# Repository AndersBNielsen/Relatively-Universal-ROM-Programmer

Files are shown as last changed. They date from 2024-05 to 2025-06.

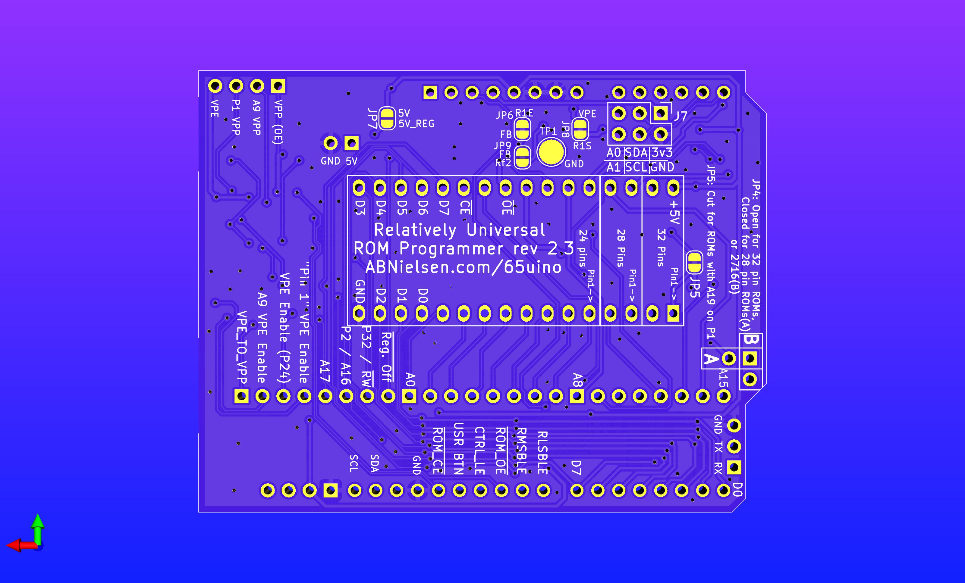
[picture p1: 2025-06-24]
hardware/RelativelyUniversalROMProgrammerRev2.3-back.jpg

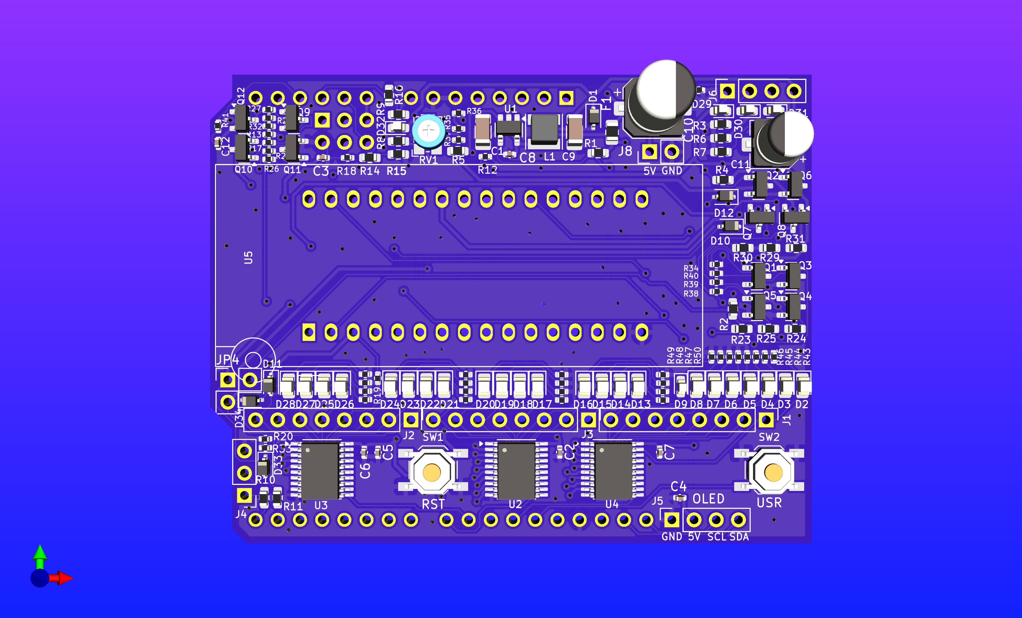
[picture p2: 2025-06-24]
hardware/RelativelyUniversalROMProgrammerRev2.3.jpg

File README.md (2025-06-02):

# Relatively Universal-ROM-Programmer
 
This is meant to be a cheap way to program W27C512 EEPROMs which require 14V erasure voltage and 12V programming voltage... Or basically any other 24/28/32 pin ROM requiring from 5V to 27V programming/erasure voltage. 

You can either make your own, get a PCB from JLCPCB using the guide below or order a kit with SMD components presoldered from [iMania.dk](https://www.imania.dk/index.php?currency=EUR&cPath=204&sort=5a&language=en) (sockets available if needed).
Kits with SMD components presoldered are available from my store, [iMania.dk](https://www.imania.dk/index.php?currency=EUR&cPath=204&sort=5a&language=en)

Requires a dev board with a processor or microcontroller. Like a [65uino](https://github.com/AndersBNielsen/65uino) or Arduino Uno for instance. 

## Software

#1 Don't attach the Programmer shield while power is on.

#2 Don't turn on power if the controller (Arduino/65uino/Nucleo board) isn't programmed with appropriate firmware. 

#3 Don't insert a ROM in the socket until you're ready to write it. Don't leave a ROM in the socket during reset or programming. 

### Firestarter firmware
If you just want to get started fast, there's an amazing third party firmware and desktop software available in the form of Henols's [Firestarter](https://github.com/henols/firestarter)
Firestarter is recommended if you just want to program ROMs cheaply, easily, and don't care too much about the technical details. 

Remember: Don't insert a ROM in the socket until you're ready to write it. Don't leave a ROM in the socket during reset or programming. Program Arduino before attaching shield. Attach shield before powering on Arduino. 

### Original proof of concept code

6502 assembly code is available in the [65uino repo](https://github.com/AndersBNielsen/65uino) (to be separated and moved here "soon"). 

Arduino sketch is available in this repo's [/software](https://github.com/AndersBNielsen/Relatively-Universal-ROM-Programmer/tree/main/software/Arduino/ArduinoProgrammerFirmwarePrototype)

Both the 6502 firmware (65uino) and the Arduino sketch use the command line python scripts in this repo for burning and reading ROMs. 

read_binary.py reads a ROM via serial. 

send_binary.py burns a ROM via serial.

send_command.py issues commands (erase for instance)

## Rev 0 photos (The Rev 1 added a voltage divider for reading VPP/VEP, Rev2 has replaced the jumpers with transistors for automatic pin count selection)

Relatively-Universal-ROM-programmer-rev0-front-assembled
Romprogrammer-assembled-back
ROMprogrammer-assembled

## Documentation
The Relatively Universal ROM Programmer relies on the standard JEDEC ROM footprint and common "high voltage" pins to work. BJT drivers handle putting the 12-27V programming voltage on the relevant pins. Which "high voltage" pins are active can be selected in software and BJT drivers control which pins can be used as VCC. 
The 12-27V for programming is manually set using a small screwdriver and a trimpot with a readout in software or multimeter if your micro doesn't have analog pins (65uino).

## Jumpers

### Revision 2.X
Revision 2 and later doesn't need physical jumpers to select 24, 28 and 32 pin ROMs, as it has transistor drivers to pass either VCC or the appropriate address line to the correct physical pin.

Revision 2 and 2.1 *do* however have a jumper to connect high voltage to pin 1 of 28 pin ROMs (JP4) - do *NOT* leave this jumper in place when programming 32 pin ROMs as it will most likely damage the ROM, the programmer, or both. 

JP4

Revision 2.2 also has JP4 but rotated 90 degrees (green) and another option of powering the VPP pin of 2716-type ROMs (red). 
Again: *DO NOT* leave JP4 in place in either rotation if you are not programming 28 pin ROMs with VPP on pin 1 (check the ROM's datasheet or "firestarter info") or 2716 type ROMs with a very nonstandard VPP pin. 



### Revision 1.x
Revision 1.x require physical jumpers to connect VCC to 24 and 28 pin ROMs

A common configuration is to connect "A" to 5V and B to "A13", which covers the Winbond 27C512 and many other common 28 pin ROMs. This configuration also covers the 32 pin SST39SF010 (5V programmable).

Documentation is on the back of Revision 1.x boards


### Setting the voltage 

The "high voltage", VPE, is calibrated using the trimpot on the front of the board after activating the regulator in software. Please be aware that some dev boards WILL put VPE on several pins during reset - especially if reset is held down manually. This MAY damage a chip in the socket (especially if it's only 5V programmable). 
Clarity: It's best to NOT reset the controller with a ROM in the socket to be on the safe side. 

Documentation will be updated with FAQ.

Programmer-back-documentation

## Getting a PCB
This project is kindly sponsored by JLCPCB. They offer cheap, professional looking PCBs and super fast delivery.

Step 1: Get the gerber file zip package from the /hardware folder
/hardware/rev2/rev2-1316.zip for instance.

Step 2: Upload to JLCPCB [https://jlcpcb.com](https://jlcpcb.com/?from=Anders_N)

Upload

Step 3: Pick your color, surface finish and order.

Select settings

Save your choice

If you want JLCPCB to assemble a board, the BOM and placement files are also in the repo. 

You can use these affiliate links to get a board for $2 and also get $80 worth of New User Coupons at: https://jlcpcb.com/?from=Anders_N

And in case you also want to order a 3D-printed case you can use this link. 
How to Get a $7 3D Printing Coupon: https://jlc3dp.com/?from=Anders_N

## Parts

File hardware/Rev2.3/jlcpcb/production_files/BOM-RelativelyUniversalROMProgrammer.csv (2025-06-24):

Comment | Designator | Footprint | LCSC | Quantity
10uF | C1,C9 | C_1206_3216Metric | C13585 | 2
28/32 pin ROM | U5 | DIP_Socket-32_W11.9_W12.7_W15.24_W17.78_W18.5_3M_232-1285-00-0602J | C146583 | 1
100nF | C12,C2,C3,C4,C5,C6,C7,C8 | C_0402_1005Metric | C1525 | 8
MIC2288 | U1 | SOT-23-5 | C181783 | 1
1N5819 | D1,D10,D11,D12,D33,D34 | D_SOD-323 | C191023 | 6
MMBT3904 | Q1,Q11,Q3,Q4,Q5,Q9 | SOT-23 | C20526 | 6
220uF | C10 | CP_Elec_6.3x7.7 | C22388053 | 1
RED | D29,D30,D31,D32,D9 | LED_0603_1608Metric | C2286 | 5
GREEN | D13,D14,D15,D16,D17,D18,D19,D2,D20,D21,D22,D23,D24,D25,D26,D27,D28,D3,D4,D5,D6,D7,D8 | LED_0805_2012Metric | C2297 | 23
10k | R12,R19,R20,R21,R33,R41,R43,R44,R45,R46,R47,R48,R49,R50,R51,R52,R53,R54,R55,R56,R57,R58,R59,R60,R61,R62,R63,R64,R65,R66 | R_0402_1005Metric | C25744 | 30
4k7 | R13,R17,R18,R22,R26,R27,R28,R32,R34,R35,R36,R37,R38,R39,R40 | R_0402_1005Metric | C25900 | 15
74HC573 | U2,U3,U4 | TSSOP-20_4.4x6.5mm_P0.65mm | C3151971 | 3
RST | SW1,SW2 | SW_SPST_TL3342 | C318884 | 2
10uH | L1 | L_Taiyo-Yuden_MD-4040 | C497774 | 1
Polyfuse | F1 | Fuse_0805_2012Metric | C516070 | 1
MMBT3906 | Q10,Q12,Q2,Q6,Q7,Q8 | SOT-23 | C7420354 | 6
50k | RV1 | Potentiometer_Bourns_TC33X_Vertical | C913246 | 1
VP | J6 | PinSocket_1x04_P2.54mm_Vertical |  | 1
Conn_01x02 | J8 | PinHeader_1x02_P2.54mm_Vertical |  | 1
22k | R25 | R_0603_1608Metric |  | 1
MSB | J2 | PinHeader_1x08_P2.54mm_Vertical |  | 1
270k | R16 | R_0603_1608Metric |  | 1
22k | R14 | R_0603_1608Metric |  | 1
1k | R11 | R_0603_1608Metric |  | 1
NC | C11 | CP_Elec_5x5.4 |  | 1
22k | R7 | R_0603_1608Metric |  | 1
LSB | J3 | PinHeader_1x08_P2.54mm_Vertical |  | 1
22k | R6 | R_0603_1608Metric |  | 1
1k | R10 | R_0603_1608Metric |  | 1
CTRL | J1 | PinHeader_1x08_P2.54mm_Vertical |  | 1
OLED | J5 | PinSocket_1x04_P2.54mm_Vertical |  | 1
22k | R4 | R_0603_1608Metric |  | 1
22k | R8 | R_0603_1608Metric |  | 1
22k | R2 | R_0603_1608Metric |  | 1
22k | R1 | R_0603_1608Metric |  | 1
22k | R3 | R_0603_1608Metric |  | 1
22k | R30 | R_0603_1608Metric |  | 1
22k | R23 | R_0603_1608Metric |  | 1
22k | R24 | R_0603_1608Metric |  | 1
22k | R31 | R_0603_1608Metric |  | 1
22k | R29 | R_0603_1608Metric |  | 1
Ext_UART | J4 | PinHeader_1x03_P2.54mm_Vertical |  | 1
22k | R15 | R_0603_1608Metric |  | 1
22k | R9 | R_0603_1608Metric |  | 1
270k | R5 | R_0603_1608Metric |  | 1
TestPoint | TP1 | TestPoint_Pad_D3.0mm |  | 1
SAO | J7 | PinHeader_2x03_P2.54mm_Vertical |  | 1

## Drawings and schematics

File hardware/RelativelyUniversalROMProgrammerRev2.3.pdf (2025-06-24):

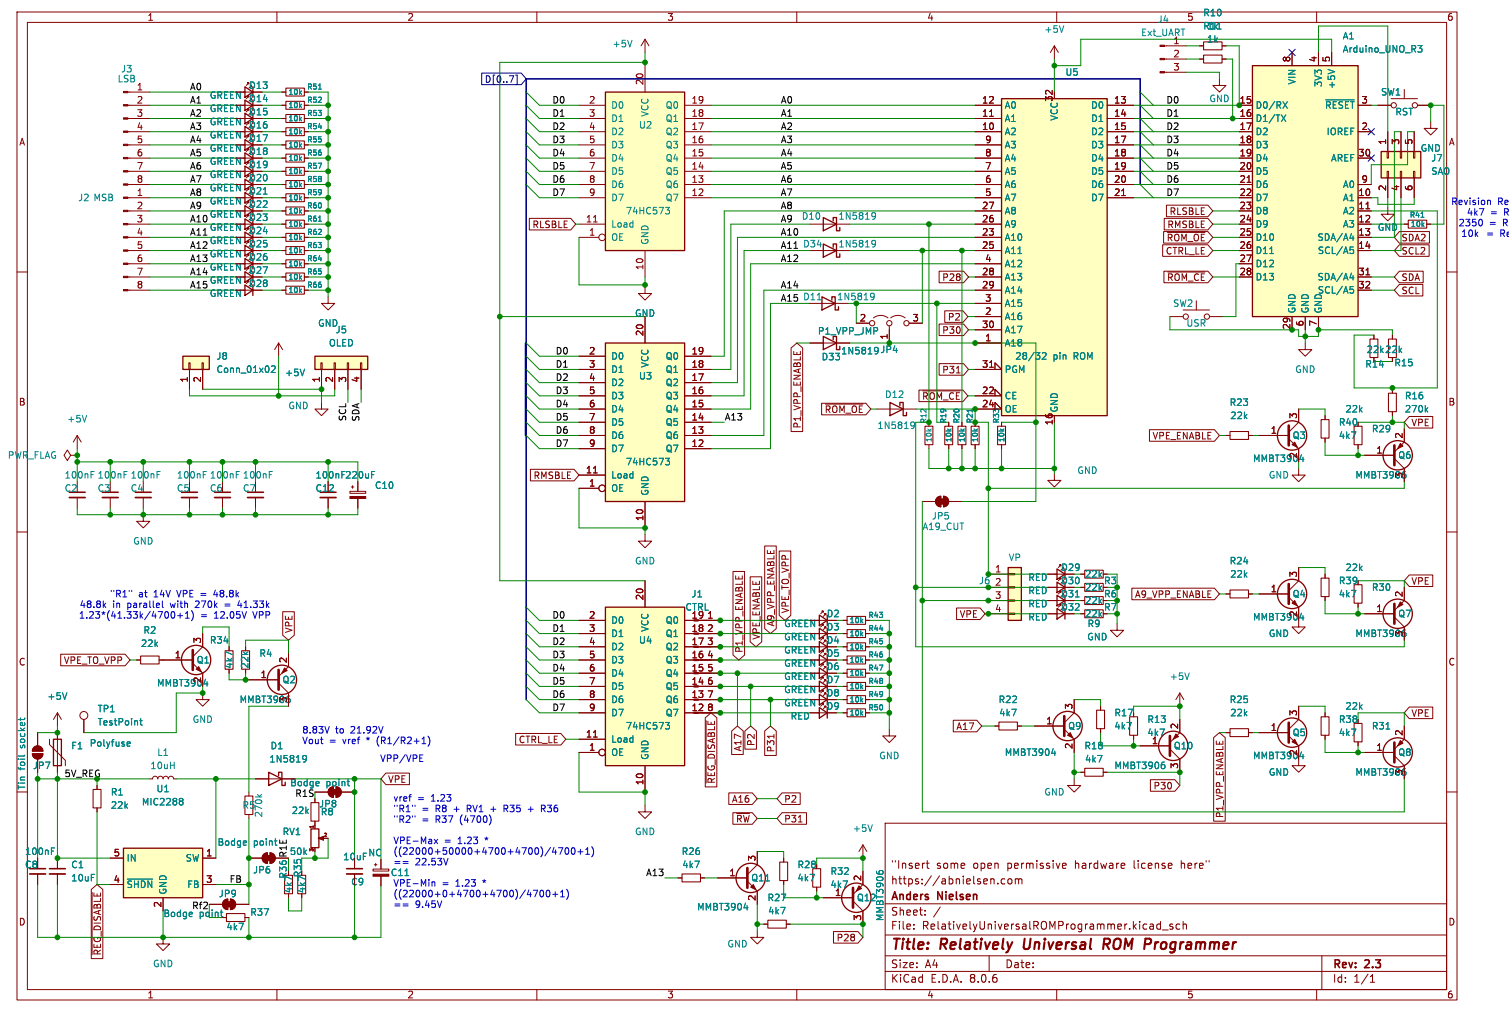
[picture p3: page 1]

~{RESET}3 AREF 30 SDA/A4 31 SCL/A5 32 3V3

A1 10 A2 11 A3 12 SDA/A4 13 SCL/A5 14 D0/RX 15 D1/TX 16 D2 17 D3 18 D4 19

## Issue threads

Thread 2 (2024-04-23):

Change github About

AndreiCherniaev, 2024-04-23:
I suggest to add About text (right top corner of github)
_Hardware to program W27C512 EEPROM or any 24/28/32 pin ROM requiring from 5V to 27V programming voltage._

I also suggest you to add tags:
**chip-programmer
prom-writer**

Closed 2024-04-23.

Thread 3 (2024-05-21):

Please please please replace the Micro-USB connector with a USB-C connector 🙏🏾

volkertb, 2024-05-21:
Hi Anders,

I just watched your announcement on YouTube, and first of all: a big THANK YOU for releasing this project with the world! :hugs:

I remember a few years ago having to find a good USB ROM programmer on-line that would come with open source Linux drivers. Although I eventually found one, it was not easy. Nor was it cheap, even for a used one.

So having a programmer that has both an open source hardware design and open source software support is really the best of both worlds. And for such a low price too! Your contribution will indeed help a lot of hobbyists, tinkerers and perhaps even some professional electronics engineers worldwide!

But I have to admit that while watching your video, there was one thing that broke my heart. And no, it wasn't the red LEDs.

The Micro-USB connector. :scream: Is there any deliberate reason why you picked it over USB-C?

There appears to be enough space in the corner to accommodate a USB-C connector instead. And it might increase the total costs of the design by a little, but I cannot imagine that it would be that much more expensive.

I don't think I have to rattle off all the advantages that USB-C has over the abomination that is Micro-USB. I think that's all pretty obvious.

Say what you will about those expensive commercial ROM programmers, but those old-school USB Type B connectors sure were durable and sturdy. I know that a Type B connector on your programmer design would probably be overkill, but please consider using USB-C in your design instead.

If there is any reason why this wouldn't be feasible, maybe you can explain in this thread?

Thanks again! Looking forward to seeing this project improve and thrive. :heart:

bleroy, 2024-05-21:
Maybe I'm missing something, but I'm pretty sure the USB connector is on whatever Arduino clone you choose to use with the board, not on the programmer board itself. Soooo.... pick a board with USB-C?

volkertb, 2024-05-21:
Ah, you're right. It goes on top of another board as a HAT. I should have realized that. :man_facepalming:

Sorry for the misunderstanding, then. In case you hadn't noticed, I hade the Micro-USB connector like the plague and got immediately triggered when I saw it as part of a new project. :sweat_smile:

Thanks for clarifying!

Closed 2024-05-21.

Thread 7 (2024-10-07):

Read ROM command not working without serial delay

BizarroBull, 2024-10-07:
When a read command is sent to the arduino, it reads a block, begins serial connection with the host, writes the header byte 0xAA, writes the block, and ends serial communication.

However, for me the header byte is never sent correctly. I have to add a `delay(50);`.

Is that expected after the `readAddress(cAddr)` calls?
I see that delay call is already there for the burn rom command and talks about settling.

AndersBNielsen, 2024-10-08:
I might be a bit sleepy but I can't seem to grasp what you are trying to do - 50ms is an eternity.  Are you using the read_binary.py script?

What exact steps are you taking to reproduce the issue?

BizarroBull, 2024-10-09:
I've created a small java gui app and I'm doing the equivalent of read_binary.py. I send the bytes to my arduino to read the ROM.

The arduino receives my bytes properly, but when it writes 0xAA followed by the block of data, the 0xAA is received in my java app as garbage. I believe the block of data is received correctly but my app ignores it since it never received 0xAA. I think it's only the first byte that isn't sent correctly.

When I add the 50ms delay, the app receives the 0xAA and the block of data correctly.

Yes, 50 ms really slows it down. I haven't tried reducing the delay further. I was hoping you might have some insight to why it would be needed and what the minimum delay would need to be.

AndersBNielsen, 2024-10-09:
Remember the Arduino resets when you open the port - that’s why it has a
long delay in the beginning.
Next you want to make sure you empty the serial buffer of all the junk
while waiting for 0xAA.
One byte at a time.

I assume you checked read_binary.py works with your Arduino and OS?
Serial kinda has a tendency to be handled differently :/

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

BizarroBull, 2024-10-09:
I wait after opening the port so that's not the issue.
My java app is emptying the serial buffer but it never receives the 0xAA byte. It receives garbage in its place.
I haven't tried your read_binary.py script. I will install python and try that.

I was thinking this was an issue with sharing pins 15 and 16 of the Arduino. Aren't the other delays in your code related to that?

BizarroBull, 2024-10-09:
I have the same problem using your python script instead of my java app. It works with my delay. It doesn't work without it.

Any thoughts?

AndersBNielsen, 2024-10-09:
Where do you insert the delay?

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

BizarroBull, 2024-10-09:
See the `delay(50);` statement in the code below:

```
      if (currentCommand.command == 0x01) {
        //Dump ROM via serial
        currentCommand.blockSize = Serial.read();
        byte cAddrL = Serial.read();
        byte cAddrH = Serial.read();
        cAddr = cAddrH << 8;
        cAddr |= cAddrL;
        romsize = (static_cast<uint32_t>(Serial.read()) << 8); //Reads stoppage a.k.a. the high byte of ROM size
        if (romsize == 0) romsize = 65536; //Need a fix to support A17+
        Serial.end();
        display.clearDisplay();
        display.print(F("Sending ROM via serial..."));
        display.print("Blocksize: ");
        display.print(currentCommand.blockSize);
        display.display();
        for (int i = 0; i < romsize/currentCommand.blockSize; i++) {
          // Read data into buffer
          for (uint16_t addr = 0; addr < currentCommand.blockSize; addr++) {
            buffer[addr] = readAddress(cAddr);
            cAddr++;
          }
          Serial.begin(baudrate);
          // delay(50); // Delay needed for Serial.write fix?
          Serial.write(0xAA);
          for (uint16_t addr = 0; addr < currentCommand.blockSize; addr++) {
            Serial.write(buffer[addr]);
          }
          Serial.end();
        }
      }
```

BizarroBull, 2024-10-10:
Would it have anything to do with the VEP (12.75V) and chip (ST 27C256) I'm using?

Is it worth watching the Arduino's D1 / TX pin with a logic analyzer while doing the readAddress followed by the Serial.begin/write?

AndersBNielsen, 2024-10-10:
You actually DO need some sort of delay there - but on the order of 1ms,
not 50.
Your serial has to time out or read a byte and stay high long enough to be
registered as inactive for the start bit to be registered correctly.
Your chip should work, easily :)

Would be helpful if you double check what’s going on in hw

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

BizarroBull, 2024-10-11:
I've moved the delay before the Serial.begin call. It works with a 1ms delay. Here you can see the read from the ROM chip, a 1 ms delay, then transmitting the data:

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

Without the delay the 0xAA looks like it's transmitted properly. My logic analyzer shows a framing error so the host receiving the data must have the same problem:

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

I can't tell from the images where the Serial.begin call was. The voltage could still be changing at that point.

AndersBNielsen, 2024-11-16:
Exactly. After transmitting junk it needs a whole frame of stop condition to know when to start.
I guess this is cleared up and this can be closed - or is it missing somewhere it should be?

BizarroBull, 2024-11-20:
The delay call needs to be added to your code.
In my comment above I show delay(50); as a comment after calling Serial.begin(baudrate).
I think it should be delay(1); BEFORE calling Serial.begin(baudrate).

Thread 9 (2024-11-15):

V2 Bom questions

tuctboh, 2024-11-15:
Hi,

Trying to get this into JLCPCB. The board was fine and I could make some changes to colors/etc, but theres BOM issues -

C11 - It says the value is NC, does this mean its not actually needed?
J5/J6 - Having an issue finding "Connector_PinSocket_2.54mm:PinSocket_1x04_P2.54mm_Vertical"
J7 - Says its not in the CPL file so they don't know how to place it
U5 - http://ww1.microchip.com/downloads/en/DeviceDoc/25022B.pdf isn't a valid url. Is the 232-1285-00-0602J the only one that can be used, they're saying its $65 each and not in stock.

Thanks, Tuc

tuctboh, 2024-11-16:
Would it also be possible to get a BOM/CPL with the bottom items populated too?  Tnx

AndersBNielsen, 2024-11-16:
There are no bottom items to be populated except for the pinheaders(which I suggest doing by hand because it's easy and it makes the board so much cheaper), so you can simply skip those. U5 is the main socket, so also a "do not place".
Be sure to deselect the headers for assembly.

Let me know if that's not enough info to get you going :)

tuctboh, 2024-11-16:
> There are no bottom items to be populated except for the pinheaders(which I suggest doing by hand because it's easy and it makes the board so much cheaper), so you can simply skip those. U5 is the main socket, so also a "do not place". Be sure to deselect the headers for assembly.
>
> Let me know if that's not enough info to get you going :)

Thanks. But I'm still looking to know -

C11 - The value says NC, does this mean its not added? It's showing up as not able to source.
J5/J6 - Do you have a better part number or description for this?
J7 - Not in the CPL file, so they don't know how to place it.
U5 - They're saying its out of stock, and its 63$ a piece. Is there a better replacement for this?

 Bottom pins+U5 - I'm not that great a solderer, so was hoping to get them to build a complete unit with no soldering needed. Is it possible to create a BOM for that.

Thanks, Tuc

AndersBNielsen, 2024-11-16:
NC means “No connect” aka don’t place.

The other pin headers you mention are debugging and not strictly needed.

It’s not that easy to have JLC solder the pins for “A1” which is the shield
pins going into the Arduino.
You might want to contact them about it - it might be expensive.

U5 is the main socket and it’s up to you if you want a generic 15.24mm wide
32 pin socket or a ZIF.
JLC don’t have ZIFs so you’ll have to send it to them.

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

tuctboh, 2024-11-16:
NC - Ok, thanks.
J5/J6 - Gotcha, but still, would rather have a COMPLETE unit incase there is a time I want to debug something stupid I did. ;)
A1 - Thanks for the heads up, I'll talk to them about it. I still would need the CPL and BOM for it.
U5 - SIGH. Ok, thanks. $63 a pop, that's unreal. (Though at 200 it goes down to 28. ;) ).

I appreciate you putting up with this. I'm trying to come up with the order as "Ready to slap onto an Arduino Uno". (Except for the INO).

Thanks, Tuc

AndersBNielsen, 2024-11-17:
I don’t know what you’re talking about with U5 :) It’s just a socket that
has a “U” designator because of the schematic - costing cents.

I’ll give it an update with LCSC part numbers for the headers.

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

tuctboh, 2024-11-18:
So this is where things stand -

A) Uploading BOM/CPL says there is no J7 in the CPL. I realize this is a test header, but maybe in the "EVERYTHING" BOM/CPL would be nice to have it added.
B) R1,R2,R3,R4,R6,R7,R8,R9,R12,R14,R15,R19,R20,R21,R23,R24,R25,R29,R30,R31 - They're saying that the description doesn't match the part (0603WAF2202T5E) but it seems fine
C) R5,R16 - Same (0603WAF2703T5E) but also seems fine
D) R10,R11 - Same (0603WAF1001T5E) but seems fine
E) J4 - Seems an issue now, says its 1) Out of stock 2) Doesn't think its coming up with the right piece (1125-1103S0S113CR01)
F) C11 - Doesn't like the NC, is there some other way to identify it as not connected or just removed?
G) J5/J6 - I realize this is a test header, but again for the EVERYTHING BOM/CPL would be nice to have it added.
H) U5 - It didn't find the part. It looks like its looking for the 3M 232-1285-00-0602J. If I hit "Search" and put that in, it tells me that "*For qty≤5,charges a fixed fee $315.1905 " which means $63.0380 a piece! I can't seem to find anything in stock thats a 32P ZIF 2.54" . I clicked "Pre-Order" and now realize I can get them to order them, which is a bit odd but ok.  I went back to J4 to see what I can do, and because its an Inventory Shortage I can only substitute something from them, they don't give me the option to pre-order.
I) For the underside, it would be really nice if those could also be added to the "EVERYTHING" BOM/CPL. (A1 you called it I think)

Sorry I'm being a total n00b, but really interested in having this come pre-assembled and ready to go!

Thanks so much for your patience and help!

AndersBNielsen, 2024-11-22:
You've got it wrong about U5.  It's a socket but I've used the SST part as an example of what could go into the socket and template for the pinout. I've updated the BOM accordingly in the rev2 folder to a 32 pin DIP socket - you can optionally put a ZIF socket on top of that with no soldering if you get the right kind. If you want JLC to solder a ZIF for you, you will have to source it yourself, and ship it to them.

The resistors are the basic ones and they change from time to time. Usually JLC has no trouble picking out the correct ones. Make sure you compare everything matches the schematic and correct footprint either way.

None of the headers you mention are strictly required. If the one it defaults two is stuck as out of stock you can select a random part in stock and then deselect it.

I will not be adding extra headers to the BOM or CPL - it's messy and this project is supposed to come without those presoldered anyway.
If you want to make the change yourself you will have to add the 2 x 8 pin, 1 x 10 pin, and 1 x 6 pin header - either "on top" of A1 and connected to the correct nets in the schematic, or by removing A1 and redoing all the connections and the board outline.
Maybe you can get away with adding them unconnected and exporting the CPL but DRC will probably complain.

tuctboh, 2024-11-25:
Hi,

Thanks for the reply. I reached out to someone on Fiverr and got them to do what I needed, thanks. I put the order into PCBWay since they were a lot easier to deal with about this than JLC. I should have 5 of these coming soon and they'll be available for sale either as just a hat or complete with an Arduino. Look forward to it!

tuctboh, 2024-12-11:
Hi,

After taking a while to source the parts, the first attempt has been made. Its 3am here and I can't sleep so I'm posting but will take a closer look and compare to yours when I'm fully awake.

What do you think? Anything look obvious? They're always very concerned about the LEDs, is there a "standard" you followed (Anode always on top or left, etc) to verify? Otherwise, the jumpers on the bottom that don't interface to the Arduino concern me, I'm not sure there will be clearance. Any comments are appreciated.

Of course, I'll also need to test this. Do you have a well known chip and code that could be used as an example to see that it programs and reads?

THANKS!

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

tuctboh, 2024-12-11:
Forgot to @AndersBNielsen you.

AndersBNielsen, 2024-12-11:
@tuctboh  Looks reasonable. It looks like the LED's are in the correct position to me. You will have to check the PCB in kiCAD, netlist or position file if in doubt about component orientation.

Like I mentioned before J1, J2 and J3 should not be mounted unless you specifically need them.
If you are using a controller with a USB-B socket, you will need to isolate J1 to avoid shorting it to the B socket. A piece of kapton or electrical tape will usually do.

If you're using an Arduino Uno there's also no point in mounting J4.
J6 is usually only used as test points and shouldn't have be mounted either.

I also see you've started mounting the SAO header on the wrong side of the board. I have no idea if that will be in the way of anything underneath. Probably - it certainly won't be usable on the bottom.

Looks like you have a lot of headers soldered you don't need, but haven't finished soldering the Arduino pinout headers.

Unless the SAO header is in the way of something, it'll probably work just fine.

For a working unit, all you actually need are the Arduino pinout headers and the main socket.

tuctboh, 2024-12-11:
@AndersBNielsen  - Thanks so much for looking it over and all the mentions -

Additional un-necessary headers - They're there, might as well fill the holes. ;)
J4 - Might use the 65duino, so wanna keep options open.
J1 - THANKS! Very good information, will handle it with tape
SAO - Yea, I thought that looked wrong. It wasn't in the CPL and when we added it it was mistakenly marked bottom instead of top. Will get this resolved, THANKS
Finished soldering - Yea, this isn't finished, things were just in place, especially U5 since they weren't aware which way the ZIF needed, and if things were right otherwise.

I've given them feedback and they'll tweak it and then finish all the soldering. THANKS AGAIN!

tuctboh, 2024-12-11:
@AndersBNielsen - FEMALE?! UGH. :-/ Thanks.

Also found out why it ended up on the bottom. Apparently my tech re-generated the CPL from your source files and it's apparently marked bottom there. Might want to correct it there. I saw you had a "Bottom" file you deleted back in October, maybe the changes to the source didn't get made at the same time.

AndersBNielsen, 2024-12-11:
The footprint comes from the SAOs that plugin to it - hence the footprint
marked as bottom.
But again - it’s only supposed to be assembled manually if you have a SAO
to plugin or want to use the pins other ways. And some people do.

Did you have it made in time for rev 2.1 or is it a 2.0 build?

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

tuctboh, 2024-12-13:
@AndersBNielsen - I didn't realize it had a keyed socket. (I didn't know SAO was a thing) I already approved just a 2x3 pin header socket. Again, want to keep options open and do it now so it doesn't need to be touched otherwise for any reason.

Rev 2.1? I don't see a rev 2.1 in github. Where is that?

tuctboh, 2024-12-19:
@AndersBNielsen - ?? ^^ ?? - Also, is there a discord to support this project?

AndersBNielsen, 2024-12-20:
The SAO socket is meant *either* as a SAO socket or for individual use cases - like if you wanted to use it as a secondary UART. If you don't have a SAO or a use case, you might shooting yourself in the foot by mounting something. Same for the debugging headers, since they're generally meant as probe points that *can* be used to mount headers for very special cases.

There's an invite to the Hackerspace Clubhouse clubhouse Discord server in any somewhat recent video of mine from the last year (if I post here I won't update if it expires) - here's one: https://www.youtube.com/watch?v=LWYeSAVNEWM

2.1 was in the "Fused" branch - I've finished testing it, so I just merged to main.

This the original BOM questions have been covered, files have been updated, so I'm closing this issue.

You're welcome to join the Discord and ask tons of questions like this :)

Closed 2024-12-20.

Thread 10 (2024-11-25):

Electrical Issue - If the Vpp adjustment trimmer looses contact, the Boost Converter goes into a run-away and shorts the supply rails.

Kuba0040, 2024-11-25:
Hello, Mr. Andreas

I apologize for how long this message is, however I couldn’t find any contact information to send You an email about this with my detailed suggestions on how to fix all these issues.

I have purchased the rom burner from Your store, and it is great, thank you so much for making it! In the process of testing it however, I accidentally used too much force while adjusting the Vpp trimmer, causing it to bend out of shape. **This caused the trimmer’s wiper to lose contact with the resistive trace which sent the boost converter into a run-away** _(trying to **boost the voltage to infinity**)_. The coil got very hot, and the circuit shorted out the Arduino’s power rails. This is caused by the Boost Converter loosing all feedback when the trimmer fails.

I have reviewed your schematics and would like to suggest this improved design _(Please consult file New Design.png_).
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

As You can see, it uses no extra components, however, just re-arranges them. The trimmer is still being used as an adjustable resistor within the voltage divider, however now it is the top resistor and the potentiometer’s full resistive track is connected. In function, this works the same way as Your design.
When the trimmer’s is turned to one side and it’s resistance is 0Ω and the output voltage is minimum _(I forgot to add a second resistor in the schematic, in series above the potentiometer, like You have done in Your design to set what that minimum voltage is, without it the minimum voltage would be whatever the Boost Converter’s reference voltage is, I apologize for the mistake before scanning)_, when the trimmer is fully tuned the other way, and it’s resistance is at maximum, the output voltage also is at it’s maximum value.
**However critically, if the trimmer’s wiper were to lose contact, the output voltage would be safely boosted to the maximum value we design**, the same as if the trimmer were set to the maximum position. In general, I’d also highly encourage you to substitute the miniature trimmer for a higher quality, and bigger one to make it more reliable. Right now, if the trimmer were to fail completely, it would be quite difficult to fix the programmer, especially for people with beginner soldering skills. It would be more expensive, but vastly better.

**-- End of Relevant Issue as mentioned in post title, the following is an design suggestion on how to control Vpp automatically, with the Arduino --**

Another question **I’d like to ask is weather having the Vpp trimmer was a conscious design choice or rather a limitation**, not being able to adjust Vpp automatically with the Arduino. If so, I’d also like to offer a potential solution _(Please consult file Automatic.png)_:
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

The circuit below uses an Operational Amplifier to compare the boosted Vpp to a set-point dictated by the Arduino. The Arduino is of course a digital device and thus cannot create arbitrary voltages at its pins. **We can cheat however and use PWM**. In this circuit, the arduino’s PWM signal is heavily filtered to create a mostly smooth, although a little bumpy DC voltage, proportional to the PWM duty cycle. The higher the duty, the higher the filtered voltage. Just how bumpy the filtered voltage is is a design choice, with more filtering the Vpp rail will be more stable, however changing its voltage will take more time.

The two feedback resistors Rf1 and Rf2 simply divide down the boosted Vpp to the 0-5V range of the Arduino’s filtered signal.

**I would also like to say that this solution may not work with all boost converter ICs**, depending on how their feedback circuitry is designed, however I don’t think it would cause problems with the one You’re using. In terms of the Op-Amp itself, while I can’t speak for all manufacturers – single, tiny SMD op-amps can be bought very cheaply from makers like Nisshinbo and Toshiba. J**ust be careful in your choice that the Op-Amp can work with its output and inputs close to the negative rail (0V).** Some op-amps may not be able to do so or deceptively appear like they can't, but in fact can work like that. A good example is the NJM2904. By simply installing a resistor going to ground from its output, we’re forcing it to always supply current, never sink it – and thus allowing it to lower its output all the way down to 0V. Although, depending on how high the reference voltage on your boost converter is, this may not be necessary. Without this trick, the minimum voltage the NJM2904 can sink its output to is 1.2V. I suspect other op-amps may be similar. S**o, it’s best to test Your chip of choice before using it**, semiconductor manufacturers often don’t show this information in their datasheets. I don’t know why.

In any case, I would highly encourage you to think about my suggestions as described here so that we may make the Universal Rom Burner even better.

Best Regards,
Kuba.

AndersBNielsen, 2024-11-25:
Hi Kuba
Thank you so much for taking the time to review the issue and bring up *two* possible solutions. Just today I decided to intentionally overturn the pot, to verify this issue, so you're right on time! It does indeed tend to fail open and cause the regulator to runaway - at least I think it usually turns off the regulator because it resets the MCU by bringing down the 5V rail in the process.

I'm not sure what I was thinking when I didn't connect the the third terminal - I guess I simply didn't consider the wiper "lifting" as a failure mode, but even that doesn't make much sense.

Either way - you're absolutely right. That'll be fixed in the net minor revision.

I like your second suggestion too because it keeps with the spirit of keeping the cost down. Just today we were also chatting on Discord (please join! https://discord.gg/AVHsHKCN ) and looking up i2c potentiometers, but even the cheapest would bring up the BOM cost a bit.

An opamp can be cheap enough that it doesn't matter cost-wise. However, I'd like to keep compatibility with my 6502 based 65uino - and that doesn't have PWM outputs.
Instead of relying on PWM outputs I've thought about using a fourth register as a cheap r2r DAC, since it doesn't need extra BOM items - but it might still need the opamp. I'll have to think more about that.

Thanks again for the detailed review!

henols, 2024-11-26:
@Kuba0040 Awesome write up, helped me to understand the things that are over my head!
I totally love the idea of using an OPamp and a PWM signal.
I do support @AndersBNielsen idea about not to break compatibility with 65duino, RURP is kind of sprung out of that project.
And on the other side RURP suddenly turned out to be a product instead of a tinkers tool.
Let try to figure something out to still be compatible with both ways of using RURP.

Kuba0040, 2024-11-26:
Hello,
Thank You so much for the feedback. I forgot about the 65uino in my design, I do apologize. But that being said, I think the R2R ladder DAC idea is a great one, and it **opens up a great possibility to completely get rid of the Op-Amp in the design by using just a little bit of analog magic**.

Please, take a look at the design below:
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

I have removed the op-amp, and added a third resistor connecting the R2R DAC to the midpoint of the feedback divider. **Such a resistor configuration is called a Super Position, and it may be the best solution to Your problem.**

**It works as follows:**
The normal Rf1 and Rf2 resistor divider still provides feedback to the Boost Converter, however now the DAC resistor ladder through the Rmid resistor, can slightly pull the divider’s voltage down or up. When it does so, it fools the Boost Converter into thinking the Vpp voltage is higher or lower than it actually is, and thus allows us to control Vpp.

**When the DAC output is at maximum (5V)**, it raises the feedback voltage, this means that Vpp needs to now be lower to maintain the same reference voltage at the Boost Converter’s FB pin. As a result, Vpp is brought down to its minimum value, which we design.
**When the DAC output is at minimum (0V)**, it pulls the feedback voltage down, this means that Vpp now needs to be higher to reach Vref at the feedback point. As a result, Vpp goes up to the maximum value.

**This solution could have also worked with the PWM approach**, however I chose not to describe it, as the bumpy nature of the filtered PWM signal could have led to unwanted oscillations and stability issues with the feedback, which would have required frequency compensation. Not to mention, the Super Position network would impose a load on the filter, which would also need to be considered.

The superposition + R2R approach by itself is difficult to design, the impedance of the R2R DAC would have to be calculated to be able to properly design the Super Position Divider to produce our desired Vpp range. I apologize if I have been vague on the calculation side of my ideas, however currently I don’t have much free time to run the math, properly design and test the divider and DAC for Your needs. _(It’s exam season in Poland - I’m finishing high school)_.

**I still think however that this would be the perfect solution for Your needs**, it’s cheap and very clever - fits the spirit of the Universal Rom Burner perfectly! Due to my situation however, I just don’t feel comfortable making promises to design this circuit in a timely matter.

If You’re interested in potentially incorporating this circuit into Your design, I’d highly recommend You look around for other analog engineers on Your discord server and show them my ideas. They will probably have even better ideas than me and could improve them and point out issues I didn’t even foresee here.

Thank You for considering my previous ideas, I hope this one will be of use as well.
Best of luck,
Kuba.

AndersBNielsen, 2024-12-20:
Closing as the safer pot design has been implemented and tested. @Kuba0040  Thanks for noticing!
Since I have Rev2.1 now I can start testing DAC options :D

#11

Closed 2024-12-20.

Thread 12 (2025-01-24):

3D printed case

JosipBasic, 2025-01-24:
Hi all.
Got programmer few days ago, and i want to put in case.
Link on github does lead to proper page.
Is there somewhere files for 3d print case?
Thanks.

AndersBNielsen, 2025-01-25:
Someone on the Discord did make a basic case for it, but unfortunately didn't share the files (yet, anyway).

Myself, I just use one of the many options for an Uno R3, and only use the bottom.
https://www.thingiverse.com/search?q=arduino+uno+&type=things&sort=relevant&page=1

I'll leave this open, as I suspect something will spawn eventually.

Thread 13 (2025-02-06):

No programmer found

whiterabbitpsychosis, 2025-02-06:
Hello,

I'm new with Arduino environment. However, my Arduino Uno is not recognized via Firestarter. I get this message when I enter a command ("fw", "vpp", etc...): 'No Programmer Found.' It is properly detected on the Arduino IDE, so I think it's related to the ROM programmer. It powers up correctly and my soldering is good. Is there something I might have missed?

Thanks!

AndersBNielsen, 2025-02-06:
Hi :)
Make sure you shut down the Arduino IDE(it typically puts a lock on the serial port) and remove any IC's in the socket(or the whole shield) before running:
```firestarter fw install```

Firestarter should respond even with no programmer shield attached.

If none of that get's you going, please reopen the issue over on the firestarter repo or come say hi on Discord :)
https://github.com/henols/firestarter

whiterabbitpsychosis, 2025-02-07:
Hi Anders,

Thanks for the help. Still not going.

Could you share the discord server?

Michel

Le jeu. 6 févr. 2025 à 21:59, AndersBNielsen ***@***.***> a
écrit :

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

Closed 2025-02-06.

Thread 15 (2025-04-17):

Board rev 2.1 JP4

tjjq44, 2025-04-17:
Hi, in case I want to program a 24-pin Eprom (M2732A for example), I wonder if JP4 should be open or closed? Your last video (https://www.youtube.com/watch?v=LWYeSAVNEWM) doesn't tell anything about this.

AndersBNielsen, 2025-04-17:
Hi :)
It's documented on the back of the board (see photo here: https://www.imania.dk/samlesaet-hobbyelektronik-og-ic-er-relatively-universal-rom-programmer.htm )

Since JP4 connects pin 1 of the 32 pin socket to pin 3 it doesn't matter for 24 pin ROMs - since neither of those are used when inserting a 24 pin ROM.

I'll try to improve documentation a bit on this repo as well - the firestarter firmware has jumper configuration listed for each ROM it supports, so

`firestarter info m2732a`

will tell you:

`    Jumper config (JP4 on Rev 2)
JP4 (Rev 2)    [ N/A ] : NA`

tjjq44, 2025-04-18:
Ok , thanks for the hint. "Jumper config (JP4 on Rev 2) JP4 (Rev 2)    [ N/A ] : NA" made me in trouble... In France "Not available" means that this configuration is unusable. A thing like "non relevant" or "never mind" seems more appropriate in this case ;)

I'm convinced you've made a great job, I have not received my shield yet but as fas as I'm concerned a little PDF/FAQ about how to configure things and what you can or can't do with it won't be a waste of time.

Closed 2025-04-17.

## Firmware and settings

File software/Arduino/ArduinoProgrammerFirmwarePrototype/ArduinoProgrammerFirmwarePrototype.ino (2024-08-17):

/*
 Written by Anders Nielsen, 2024
 https://abnielsen.com/65uino
 Some GPL license
*/

#include <Wire.h>
#include <Adafruit_GFX.h>
#include <Adafruit_SSD1306.h>

#define SCREEN_WIDTH 128
#define SCREEN_HEIGHT 64

#define OLED_RESET -1 // Reset pin # (or -1 if sharing Arduino reset pin)
Adafruit_SSD1306 display(SCREEN_WIDTH, SCREEN_HEIGHT, &Wire, OLED_RESET);

#define LONG_PRESS_TIME 1000  // Long press threshold in milliseconds

int menuIndex = 0;
unsigned long buttonPressTime = 0;
bool buttonPressed = false;

const char* menuItems[] = {"Calibrate VEP", "Display ROM ID", "Blank check ROM", "Erase W27C512"};
const int menuItemsCount = sizeof(menuItems) / sizeof(menuItems[0]);

const float R1 = 270.0;   // Resistance R1 in kohms
const float R2 = 44.0;  // Resistance R2 in kohms
const float V_REF = 5.06; // Reference voltage in volts
const int ANALOG_PIN = A2; // Analog pin connected to VEP

#define RLSBLE  0x01
#define RMSBLE  0x02
#define ROM_OE  0x04
#define CTRL_LE 0x08
#define USRBTN  0x10
#define ROM_CE  0x20

#define VPE_TO_VPP    0b00000001
#define A9_VPP_ENABLE 0b00000010
#define VPE_ENABLE    0b00000100
#define P1_VPP_ENABLE 0b00001000
#define A17_E         0b00010000
#define A18_E         0b00100000
#define RW            0b01000000
#define REG_DISABLE   0b10000000

uint32_t romsize = 4096; //We need to support more than 16 address bits
byte pattern = 0xAA;
uint16_t cAddr = 0;
byte buffer[128]; 
#define BUFFERSIZE 128

uint32_t baudrate = 19200;

// Define a struct to hold the command, block size, and stop page
struct Command {
  uint8_t command;
  uint8_t blockSize;
  uint8_t stopPage;
};

Command currentCommand;

// the setup function runs once when you press reset or power the board
void setup() {
  // Set pins D0-D7 as outputs
  DDRD = 0xFF; // Set all D0-D7 pins as outputs
  // Set control signals as outputs
  DDRB |= RLSBLE | RMSBLE | ROM_OE | CTRL_LE | ROM_CE;

  // Set all pins using direct port manipulation
  PORTD = 0;
  
  // Set all latch pins HIGH using direct port manipulation and disable ROM 
  PORTB |= RLSBLE | RMSBLE | ROM_OE | CTRL_LE | ROM_CE | USRBTN;
delayMicroseconds(1);
  // Set all latch pins LOW using direct port manipulation
  PORTB &= ~(RLSBLE | RMSBLE | CTRL_LE); // Set pins D8, D9, D11 low

    // Initialize the OLED display
  if(!display.begin(SSD1306_SWITCHCAPVCC, 0x3C)) {
    latchControlByte(0x40);
    for(;;);
  }
  
  delay(100); // Pause for 2 seconds

  // Clear the display
  display.clearDisplay();
  display.setTextSize(1);
  display.setTextColor(SSD1306_WHITE);
  display.println("Boot complete.");
  display.display();

  latchControlByte(0x10); //Can't latch things when serial is enabled
  Serial.begin(baudrate);

}

void loop() {
  if (Serial.available()) {
    byte incomingByte = Serial.read();
    if (incomingByte == 0xAA ) {
      while (!Serial.available()) { 
        ;; //Maybe we don't need it
      }
      currentCommand.command = Serial.read(); 

      if (currentCommand.command == 0x01) {
        //Dump ROM via serial
        currentCommand.blockSize = Serial.read();
        byte cAddrL = Serial.read();
        byte cAddrH = Serial.read();
        cAddr = cAddrH << 8;
        cAddr |= cAddrL;
        romsize = (static_cast<uint32_t>(Serial.read()) << 8); //Reads stoppage a.k.a. the high byte of ROM size
        if (romsize == 0) romsize = 65536; //Need a fix to support A17+
        Serial.end();
        display.clearDisplay();
        display.print(F("Sending ROM via serial..."));
        display.print("Blocksize: ");
        display.print(currentCommand.blockSize);
        display.display();
        for (int i = 0; i < romsize/currentCommand.blockSize; i++) {
        // Read data into buffer
        for (uint16_t addr = 0; addr < currentCommand.blockSize; addr++) {
          buffer[addr] = readAddress(cAddr);
          cAddr++;
        }
        Serial.begin(baudrate);
        Serial.write(0xAA);
        for (uint16_t addr = 0; addr < currentCommand.blockSize; addr++) {
          Serial.write(buffer[addr]);  
        }
        Serial.end();
        }
      }

      if (currentCommand.command == 0x03) {
        byte vendor = Serial.read();
        byte device = Serial.read();
        uint16_t romid = (static_cast<uint16_t>(vendor) << 8) | device;
        Serial.end();
        display.clearDisplay();
        display.println(F("Erasing ROM with ID: "));
        display.println(romid, HEX);
        display.display();
        eraseW27C512(romid);
        delay(3000);
      }

      if (currentCommand.command == 0x02) { 
        //Burn ROM from serial
        currentCommand.blockSize = Serial.read();
        currentCommand.stopPage = Serial.read();
        Serial.end();
        display.clearDisplay();
        display.println(F("Burning ROM from serial..."));
        display.print("Blocksize: ");
        display.print(currentCommand.blockSize);
        display.display();
        latchControlByte(VPE_TO_VPP | REG_DISABLE);
        delay(50); //Settle before enabling
        latchControlByte(VPE_TO_VPP | REG_DISABLE | VPE_ENABLE );
        delay(200);
        Serial.begin(baudrate);
        while (1) { 
          Serial.write(0xAA);
          while (!Serial.available()) { 
          ;; //Maybe we don't need it
           }
          // Read the block of data
          size_t bytesRead = Serial.readBytes((char *)buffer, currentCommand.blockSize);
            // Check if we've read the entire block
          if (bytesRead == currentCommand.blockSize) {
            // Process the buffer data
           Serial.end();
           delay(1);
           writefromBuffer(cAddr, currentCommand.blockSize);
          } else {
            display.println("Bad block");
            break;
          }
          Serial.begin(baudrate);
          delay(1);
          }
      }
    } 
  } else {
    handleButton();
    displayMenu();
  /*
  if (digitalRead(12) == 0) {
    Serial.end();
    enableRegulator();
    display.println("Press RST after calibrating VEP");
    while (1) {
          displayVEP();
          delay(17);
      }
    } else {
      display.print(".");
      display.display();
      delay(500);
    }
  */
  } //Serial 0xAA

} //Loop

void enableRegulator() {
  byte outputState = REG_DISABLE;  // Set REG_DISABLE bit
  // Set all pins using direct port manipulation
  latchControlByte(outputState);
}

void displayVEP() {
    // Read voltage from analog pin A2
  int sensorValue = analogRead(A2);
 // Convert ADC reading to voltage (assuming 5V reference voltage)
  float v_in = sensorValue * (V_REF / 1023.0);
  // Calculate voltage at VEP using voltage divider formula
  float v_vep = v_in * (R1 + R2) / R2;

    // Display voltage on OLED display
  display.clearDisplay();
  display.setTextSize(1);
  display.setTextColor(SSD1306_WHITE);
  display.setCursor(0, 0);
  display.println(F("Press RST to return."));
  display.print(F("VEP Voltage: "));
  display.print(v_vep, 2); // Display voltage with 2 decimal places
  display.println(" V");
  display.display();
}

//For single byte writes 
void writeByte(uint16_t address, byte data) {
latchAddress(address);
latchControlByte(VPE_TO_VPP | REG_DISABLE);
delay(50); //Settle before enabling
latchControlByte(VPE_TO_VPP | REG_DISABLE | VPE_ENABLE );
//delay(255); //What works on 65uino
DDRD = 0xFF; //Output
PORTD = data; 
PORTB &= ~(ROM_CE);
delayMicroseconds(101);
PORTB |= ROM_CE;
latchControlByte(0x00); 
}

void writefromBuffer(uint16_t addr, uint16_t len) {
  DDRD = 0xFF; //Output
  for (int i = 0; i < len; i++){
    latchAddress(addr);
    PORTD = buffer[i];
    PORTB &= ~(ROM_CE);
    delayMicroseconds(101);
    PORTB |= ROM_CE;
    addr++;
  } 
  cAddr = addr;
}

void eraseW27C512(uint16_t romid) {
if (getROMID() == romid) {
  DDRD = 0xFF;
  latchAddress(0x0000);
  enableRegulator();
  delay(100);
  latchControlByte(A9_VPP_ENABLE | REG_DISABLE | VPE_ENABLE );
  delay(500);
  PORTB &= ~(ROM_CE);
  delay(102);
  PORTB |= ROM_CE;
  } else {
    display.println("ROM ID didn't match.");
    display.display();
  }
  latchControlByte(0);
}

uint16_t getROMID() {
  enableRegulator();
  // Introduce a delay before repeating the process
  delay(50); // Adjust delay time as needed
  latchControlByte(VPE_TO_VPP | REG_DISABLE | A9_VPP_ENABLE );
  delay(50);
  byte byteRead = readAddress(0x0000);
  uint16_t romid = byteRead;
  romid = romid <<8;
  byteRead = readAddress(0x0001);
  romid |= byteRead;
  latchControlByte(0);
return romid;
}

byte readAddress(uint16_t addr) {
  DDRD = 0xFF; 
  latchAddress(addr);
  DDRD = 0; //PORTD as input
  PORTB &= ~(ROM_OE | ROM_CE);
  delayMicroseconds(5); //Let it settle a bit. Maybe a NOP would do. 
  byte val = PIND;
  PORTB |= (ROM_OE | ROM_CE);
  return val;
}

void latchControlByte(byte controlByte) {
  // Set control byte using direct port manipulation
  DDRD  = 0xFF ; // All output
  PORTD = controlByte;

// Set CTRL_LE pin HIGH to latch
  PORTB |= CTRL_LE;
  // Set CTRL_LE pin LOW to unlatch
  PORTB &= ~(CTRL_LE);
}

// Global variables to store the previous LSB and MSB values
byte prevLSB = 0;
byte prevMSB = 0;

void latchAddress(uint16_t address) {
  // Extract the least significant byte
  byte lsb = address & 0xFF;
  // Extract the most significant byte
  byte msb = (address >> 8) & 0xFF;
  //Assuming PORTD is output
  // Check if LSB has changed
  if (lsb != prevLSB) {
    // Write LSB to PORTD
    PORTD = lsb;
    // Set CTRL_LE pin HIGH to latch lower 8 bits of address (LSB)
    PORTB |= RLSBLE;
    // Set RLSBLE pin LOW to unlatch lower 8 bits of address (LSB)
    PORTB &= ~RLSBLE;
    // Update prevLSB
    prevLSB = lsb;
  }

  // Check if MSB has changed
  if (msb != prevMSB) {
    // Write MSB to PORTD
    PORTD = msb;
    // Set CTRL_LE pin HIGH to latch higher 8 bits of address (MSB)
    PORTB |= RMSBLE;
    // Set RMSBLE pin LOW to unlatch higher 8 bits of address (MSB)
    PORTB &= ~RMSBLE;
    // Update prevMSB
    prevMSB = msb;
  }
}

void handleButton() {
  if(digitalRead(12) == LOW) {
    if (!buttonPressed) {
      buttonPressed = true;
      buttonPressTime = millis();
    } else {
      if (millis() - buttonPressTime > LONG_PRESS_TIME) {
        // Long press detected
        buttonPressed = false;  // Reset button state
        handleSelection(menuIndex);
        Serial.begin(baudrate);
        delay(500);  // Prevent multiple triggers
      }
    }
  } else {
    if (buttonPressed) {
      if (millis() - buttonPressTime < LONG_PRESS_TIME) {
        // Short press detected
        menuIndex++;
        if (menuIndex >= menuItemsCount) menuIndex = 0;
      }
      buttonPressed = false;  // Reset button state
    }
  }
}

void displayMenu() {
  display.clearDisplay();
  for(int i = 0; i < menuItemsCount; i++) {
    if(i == menuIndex) {
      display.setTextColor(SSD1306_BLACK, SSD1306_WHITE); // Highlight selected item
    } else {
      display.setTextColor(SSD1306_WHITE);
    }
    display.setCursor(0, i*10);
    display.println(menuItems[i]);
  }
  display.display();
}


void handleSelection(int index) {
  //Calibrate VEP", "Display ROM ID", "Blank check ROM", "Erase W27C512"
  switch (index) {
    case 0:
          Serial.end();
          enableRegulator();
          while (1) {
                display.println(F("Press RST after calibrating VEP"));
                displayVEP();
                delay(17);
            }
      break;
    case 1:
          Serial.end();
      display.clearDisplay();
      display.setCursor(0,0);
      display.print(F("Read ROM ID: "));
      display.println(getROMID(),HEX);
      display.display();
           delay(3000);
      break;
    case 2:
     Serial.end();
     display.clearDisplay();
     display.setCursor(0,0);
     if (blankCheck() == 0) display.println("ROM is blank");
     display.display();
     delay(3000);
      break;
    case 3:
     Serial.end();
     display.clearDisplay();
     display.setCursor(0,0);
     display.println("Erasing ROM with ID 0xDA08 ");
     eraseW27C512(0xDA08);
     display.display();
     delay(3000);
      break;
    default:
      break;
  }
}

uint16_t blankCheck () {
  display.clearDisplay();
  display.println(F("Checking if ROM is blank.."));
  display.display();
  uint32_t i;
  for (i = 0; i < 65537; i++) {
    byte data = readAddress(i);
    if (data != 0xFF) {
      display.print(data,HEX);
      display.print(" found at address ");
      display.println(i, HEX);
      display.display();
      return 1;
    } 
  }
  if (i == 65537) i = 0;
  return i;
}

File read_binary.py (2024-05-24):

import sys
import time
import serial

def get_file(serial_port, baud_rate, file_path, total_bytes, block_size):
    try:
        # Open serial port
        ser = serial.Serial(serial_port, baud_rate)
        time.sleep(4)

        ser.write(b'\xAA') # Command byte
        # Send block size as a byte
        ser.write(b'\x01') # Command
        ser.write(bytes([block_size])) # Block size
        ser.write(b'\x00') #LSB
        ser.write(b'\x00') #MSB
        stoppage = (total_bytes >> 8) & 0xFF 
        ser.write(bytes([stoppage])) # Stoppage

        start_time = time.time()

        # Initialize a buffer to store received data
        buffer = bytearray()

        try:
            bytes_received = 0
            while True:
                if (ser.inWaiting() > 0):
                    # Read one byte with timeout
                    byte = ser.read(1)

                    # Check if start of frame is received
                    if byte == b'\xAA':
                        #print(".", end="")
                        # Read specified block size bytes
                        frame = ser.read(block_size)
                        buffer.extend(frame)
                        bytes_received += len(frame)  # Update total bytes received
                    
                    if bytes_received >= total_bytes:
                        break

            end_time = time.time()
            # Calculate total duration
            total_duration = end_time - start_time
            print(f"File received in {total_duration:.2f} seconds")

        except KeyboardInterrupt:
            # Handle Ctrl+C gracefully
            print("\nSerial reading stopped by user at ")
            print(bytes_received)
        
        # Write buffer to file
        with open(file_path, 'wb') as f:
            f.write(buffer)

    finally:
        # Close the serial port
        ser.close()

if __name__ == "__main__":
    # Check if correct number of command line arguments is provided
    if len(sys.argv) != 6:
        print("Usage: python read_binary.py <serial_port> <baud_rate> <file_path> <total_bytes> <block_size>")
        sys.exit(1)

    # Extract command line arguments
    serial_port = sys.argv[1]
    baud_rate = int(sys.argv[2])
    file_path = sys.argv[3]
    total_bytes = int(sys.argv[4])
    block_size = int(sys.argv[5])

    # Call the function to send the file
    get_file(serial_port, baud_rate, file_path, total_bytes, block_size)

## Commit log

2023-08-07 Now with files!
    [W27C512Programmer.kicad_pcb, W27C512Programmer.kicad_sch]
2023-09-12 Changed to 74HC373
    [W27C512Programmer.kicad_sch]
2024-03-15 Working on a breadboard
    Schematic breadboarded. Successfully programming W27C512's.
    [W27C512Programmer.kicad_pcb, W27C512Programmer.kicad_sch]
2024-03-28 Getting ready for PCB..
    [W27C512Programmer.kicad_pcb]
2024-04-01 PCB probably somewhat complete
    Completely untested PCB. Maybe it works. Maybe I should look for someone to review...
    [W27C512Programmer.csv, W27C512Programmer.kicad_pcb, W27C512Programmer.kicad_sch]
2024-04-18 Hardware release day update!
    Gerber files (zip) BOM, placement and KiCAD files as they are for Rev0
    [W27C512Programmer.csv, W27C512Programmer.kicad_pcb, W27C512Programmer.kicad_sch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]
2024-04-18 Green LED's .. yes
    [W27C512Programmer.csv]
2024-04-30 Rev1 PCB - Includes voltage divider on Arduino Analog Pin 2.
    Voltage divider on Arduino Analog Pin 2 as well as updated LCSC part numbers.. So you don't end up getting the wrong color LEDs.
    Remember to use the Rev1b0 gerber zip file and not Rev0.
    [W27C512Programmer.kicad_pcb, W27C512Programmer.kicad_sch, W27C512ProgrammerBOM-Rev0.csv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]
2024-05-15 Initial Arduino Firmware Prototype
    Arduino sketch that can enable the regulator and has some code to cycle through all addresses.
    Uses the Adafruit SSD1306 Library and REV 1 PCB with voltage divider on A2. (270k R1 + 44k R2 if you want to bodge it on Rev0)
    [W27C512Programmer.kicad_pcb]
2024-05-17 Arduino sketch now successfully reads a ROM to serial.. Slowly.
2024-05-20 Untested code for writing to W27C512 via serial
    Probably doesn't work - but wouldn't it be cool if it did?
    [ArduinoProgrammerFirmwarePrototype.ino]
2024-05-21 Erasing and programming a W27C512
    Arduino sketch now erases and programs a W27C512. 65uino python scripts need a 2 second delay to work after opening serial port (to get past a DTR reset).
    [ArduinoProgrammerFirmwarePrototype.ino]
2024-05-22 Erasing, Burning, and Reading a W27C512 now works!
    [ArduinoProgrammerFirmwarePrototype.ino]
2024-05-24 Arduino sketch enters calibration with a buttonpress
    ...and welcome home to the python-scripts for interacting via serial.
2024-05-24 Added selection menu to Arduino sketch
    It's now possible to start calibration, check the ROM id, blank check and erase a W27C512 from a menu on the programmer.
2024-06-27 Change 4k7 to 10k R for green LEDs
    [W27C512Programmer.kicad_sch, W27C512ProgrammerBOM-Rev2.csv]
2024-07-05 10k LED R
    [W27C512Programmer.kicad_sch]
2024-08-01 Update ArduinoProgrammerFirmwarePrototype.ino
    cast result of Serial.read() so it doesn't get treated as signed when bit shifting
    [ArduinoProgrammerFirmwarePrototype.ino]
2024-09-20 Fiddle with pin naming
    [W27C512Programmer.kicad_sch]
2024-10-04 Power through address lines
    [W27C512Programmer.kicad_sch]
2024-10-08 Rev2
    Hopefully this does what it's supposed to...
    [W27C512Programmer.kicad_pcb, W27C512Programmer.kicad_sch, rev2bom.csv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]
2024-10-17 Rev2
    Untested!
    [W27C512Programmer.kicad_pcb, W27C512Programmer.kicad_sch, W27C512ProgrammerBOM-Rev2.csv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]
2024-11-22 Fuse in schematic
    [W27C512Programmer.kicad_sch]
2024-11-22 U5 changed to a socket part
    [W27C512Programmer.kicad_sch, W27C512Programmerbom.csv]
2025-03-24 Plot PDF
    PDF updated
    [W27C512Programmer.kicad_sch]
2025-06-24 Rev 2.3
    2716/2516 jumper
    [BOM-RelativelyUniversalROMProgrammer.csv, RelativelyUniversalROMProgrammer.kicad_pcb, RelativelyUniversalROMProgrammer.kicad_sch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]
